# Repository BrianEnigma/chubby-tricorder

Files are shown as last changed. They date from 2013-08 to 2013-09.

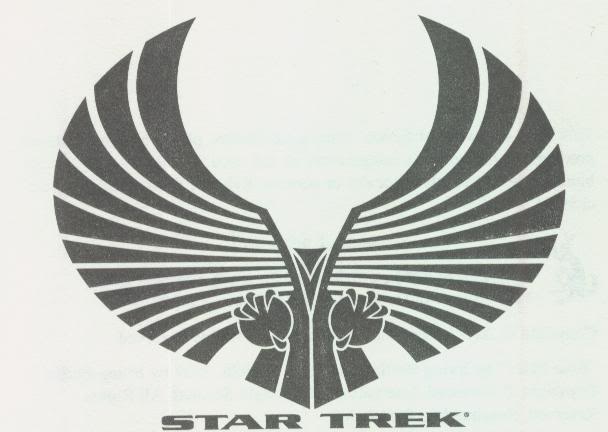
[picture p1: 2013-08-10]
Images/Inspiration/romulan2.jpg

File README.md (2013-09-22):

#The Chubby Tricorder Project



Overview goes here.

#Design Decisions

I cut some corners to accelerate development and minimize risk.  I wanted to work a few weeks of "uh oh" into the timetable as well as be able to focus on the software and presentation.  Namely:

- I used an off-the-shelf microcontroller board: the Arduino.  It's large and a little slow by microcontroller standards, but board bring-up is easy and there are hundreds of premade/pre-tested hardware accessory libraries.
- I used no batteries. The printer eats a ton of power. I didn't want to spend money on hefty batteries, which would tempt prolonged use, which in turn heightens the risk of dead batteries at a critical time.
    - Edit: I used batteries. The puzzle's location changed from indoors to outdoors, so I hacked up a battery pack.
- The case is a simple laser-cut acrylic box of a design similar to the [InfoNinja][] and my [nameplate][] using tabs, slots, and bolted mortise and tension joints. It's entirely right angles, greatly simplifying the design.

[InfoNinja]: http://netninja.com/projects/infoninja/
[nameplate]: http://netninja.com/2012/08/20/a-laser-cut-light-up-nameplate/

#BoM

- Electronics
    - [Arduino](http://www.adafruit.com/products/50)
    - [OLED display](http://www.adafruit.com/products/938)
    - [thermal printer](http://www.adafruit.com/products/597)
    - [thermal paper](http://www.adafruit.com/products/599)
    - [button pad](http://www.adafruit.com/products/419)
    - [illuminated power switch](http://www.adafruit.com/products/482)
    - [panel power connector](http://www.adafruit.com/products/610)
    - RF module
    - [5V 2A AC adapter](http://www.adafruit.com/products/276)
    - assorted bits and bobs
        - hookup wire
        - jumpers, connectors
        - solder
    - tools (soldering iron, wire strippers, diagonal cutters, hot glue gun, etc.)
- laser-cut acrylic parts TODO: public link to files. Materials: $12.00. Cutting: $17.50.
- [black 3M16 screws](http://www.mcmaster.com/#91290a120/=nzdun3)
- [black 3M nuts](http://www.mcmaster.com/#98676a100/=nzdunh)
- [black 2M10 screws](http://www.mcmaster.com/#91290a017/=nzdv42)
- [M2 nuts](http://www.mcmaster.com/#90591a111/=nzdv4x)
- [6mm M3 nylon spacers](http://www.mcmaster.com/#catalog/119/3231/=nze2y8)
- [warranty void stickers](http://www.amazon.com/Silver-Evident-Hologram-Warranty-Stickers/dp/B0049C0MNK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)

#Software Overview

Makes use of the Arduino IDE plus several 3rd party libraries:
- screen
- printer
- button matrix

#Tasks

- [X] Determine pin connections.
- [X] Wire it up on the bench:
    - [X] Test each device, individually:
        - [X] For each external device, on by one, hook it up to the default pins.
        - [X] Verify the library can communicate with the device.
        - [X] Move the device to your desired final set of pins.
        - [X] Verify the library can communicate on the new set of pins.
    - [X] Test all devices in unison:
        - [X] Start with one device, ensure it works.
        - [X] Add another, ensure they work in tandem.
        - [X] Add the next, etc.
- [X] Preliminary software
    - [X] Boot sequence animation (and also print test output on printer?)
    - [X] Data entry screen
    - [X] "Incorrect" animation (with delay to help discourage brute forcing)
    - [X] Several incorrect answers in a row has longer delay?
    - [X] Each "correct" behavior (screen, printer)
- [X] Wireless
    - [X] Transmitter and receiver Hello World
    - [X] Integrate transmitter into design
    - [X] Test with receiver
- [X] Enclosure (black 3MM acrylic)
    - [X] Determine internal parts placement.
    - [X] Preliminary laser cut pattern.
    - [X] Left/Right sides symmetric/interchangeable?
    - [X] Print on paper, verify parts fit, verify pieces interlock correctly.
    - [X] Send to Ponoko.
    - [X] Hole for reprogramming?  "warranty void if removed" sticker?
    - [X] Reinforce printer edge panel
- [X] Battery power
    - [X] Get battery holder
    - [X] Get batteries
    - [X] Wire up to 2.1mm plug
    - [X] Rewire RF to 5V regulator on Arduino
- [ ] Final software
	- [X] Image rotator with PIN entry
	- [X] RF xmission while rotating images
	- [X] Stages of image rotator
	- [X] Easter egg(s)
	- [ ] Better comments
	- [X] Licensing
	- [ ] Publish LCD assistant code separately?
    - [X] Build the more permanent RF receiver device
    - [X] Verify with RF receiver device
    - [X] Verify that one easter egg that wasn't working at meeting
- [X] "Plan B" webapp
	- [X] Basics
	- [X] All content
	- [X] Preload images - skipped; iPhone times out preloading and aborts JavaScript
- [X] Final documentation
	- [X] Prepare github
	- [X] Prepare website
	- [X] Prepare narrative blog post
	- [X] Prepare shortened URL
	- [X] Insert shortened URL plus intro text into code as easter egg

#Away Kit

In the event of a problem during the game, I'll need to assemble an "away kit" with various repair tools.

- allen wrench
- needle-nose pliers
- diagonal clippers
- multimeter
- soldering iron, solder
- helping hands

#License

The Chubby Tricorder (https://github.com/BrianEnigma/chubby-tricorder)by Brian 
Enigma (http://netninja.com) is licensed under a Creative Commons Attribution-ShareAlike 
3.0 Unported License: http://creativecommons.org/licenses/by-sa/3.0/deed.en_US

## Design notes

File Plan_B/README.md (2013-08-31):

#The "Plan B" Tricorder

In the event of a problem, this iPhone webapp can take the place of the Tricorder. Various problems might include:

- Damaged Tricorder
- We get the RF working against test devices, but the Communications Probe and Tricorder simply don't integrate and can't talk to one another.
- RF interference that prevent the two devices from working in particular locations in the field.
- Any and all other sorts of acts of the gods

So this is a webapp that will let you see the various Tricorder screens without needing to communicate via RF to the Communications Probe.

##Prerequisites

You'll need the [iUI-js][iUI] library. Running the Makefile will download, unpack, and rearrange directories for you.

[iUI]: http://www.iui-js.org/download

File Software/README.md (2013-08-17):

#Third Party Components

- [Arduino 1.0.5 IDE](http://www.arduino.cc/en/Main/Software)
- [Matrix Keypad Library 3.0 2012-07-12](http://playground.arduino.cc/Code/Keypad)
- [Adafruit Thermal Printer Library](https://github.com/adafruit/Adafruit-Thermal-Printer-Library)
- [Adafruit GFX Library](https://github.com/adafruit/Adafruit-GFX-Library)
- [Adafruit SSD1306 Library](https://github.com/adafruit/Adafruit_SSD1306)

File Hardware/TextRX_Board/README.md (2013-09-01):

#RX Test Board

This is a board that, for me, takes the place of the Tricorder. It receives signal from the RF module and displays what it has received. It's a quick test/diagnostic device, not meant for anything final. It's just nice to have the build documented and to have it on a laser-cut platform for portability.

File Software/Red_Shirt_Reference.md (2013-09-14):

#Communications Probe: Red Shirt Reference

REPRINT CODE: 911911

##Hints

The first level of hinting for each puzzle is to ensure that Curtis has identified the correct names for each image shown on the tricorder (NOT the communications probe so we preserve some puzzling for figuring out those names once the tricorder pattern is recognized). This can be done in character, “e.g. Sir, perhaps the research we’ve done could identify the names of one or two of those images for you. Which ones would you like to know more about?” followed by “Our research indicates that dog is known as a SCOTTY”. Or if he has any incorrect names, “Our research suggests the name for that image is incorrect.”

If he’s really stuck on the names for any of the communications probe images after understanding the tricorder pattern, we can give those in character as well, but only once it’s clear he understands the tricorder pattern.

##Minipuzzle 1

- Tricorder images: HERO, SAX, ORE, WINE 
- Tricorder numbers: 0, 6, 1, 9
- Communications Probe images: HOUR, NIKE, LIGHT, FILE 
- Communications Probe numbers to enter: 4, 9, 8, 5

Scheme: image name is one letter off from a digit name

Further hints:

- Sir, it looks like those tricorder lights are some kind of encoding.
- Perhaps we should compare each image to the number.
- Maybe if we spelled out those numbers we would find something.

##Minipuzzle 2

- Tricorder images: ARCHER, SCOTTY, YAR, DATA
- Tricorder numbers: 5, 1, 2, 2
- Communications Probe images: QUARK, BONES, 7 OF 9, PARIS 
- Communications Probe numbers to enter: 3, 1, 4, 4

Scheme: the series number the character is from (1=TOS, 2=TNG, 3=DS9, 4=Voyager, 5=Enterprise)

Further hints:

- Sir, our analysis suggests these are all from our universe
- Our research suggests they may be people
- In fact, you might have met Data and Yar
- I think I’ve heard the name Scotty before — wasn’t he from the generation before us?

##Minipuzzle 3

- Tricorder images: BEET, XBOX, RAFT, PEEL
- Tricorder numbers: 14, 3, 13, 7
- Communications Probe images: BATH, TAPE, BOWL, CART 
- Communications Probe numbers to enter: 14, 7, 7, 13

Scheme: The four binary bits of the numbers select letters in the word and vice-versa (beet/bee, xbox/ox, raft/rat, peel/eel, bath/bat, tape/ape, bowl/owl, cart/cat)

Further hints:

- Sir, those words all seem to have 4 letters
- Sir, our analysis suggests the tricorder may be providing some kind of mask
- Our analysis suggests it might be useful to apply the 4-light mask to each word

##Minipuzzle 4

For the initial hinting to give Curtis the full set of names, provide only the names of the items, not the color in parentheses that they suggest.

- Tricorder images: MARS (THE RED PLANET), WASP (YELLOW JACKET), FRANK SINATRA (OLD BLUE EYES), CAKE (RED VELVET CAKE, SPECIFICALLY) 
- Tricorder numbers: 1, 3, 5, 1
- Communications Probe images: SEATTLE (THE EMERALD CITY), GARDENER (GREEN THUMB), SAD PERSON (FEELING BLUE), IBM (BIG BLUE) 
- Communications Probe numbers to enter: 4, 4, 5, 5

Scheme: color indexes into the rainbow (ROYGBIV)

Further hints:

- Sir, our research suggests that the humanoid known as Frank Sinatra ha d a nickname.
- Sir, our research suggests that this may be a specific type of cake.
- We’re seeing that the planet Mars may also have a nickname.
- Some of those nicknames look quite colorful.
- If he isn’t aware of the color nicknames/names for these, provide them (e.g. Sir, it turns out Frank Sinatra was known as Old Blue Eyes).

##Minipuzzle 5

- Tricorder images: WONDER BREAD, ANALGESICS, GATORADE, GEORDI LA FORGE
- Tricorder numbers: 1, 6, 8, 4
- Communications Probe images: UNIFORM, CANINE, SKATER, TEST TUBE
- Communications Probe numbers to enter: 4, 9, 8, 2

Scheme: number contained in the phonemes of the words (Gateorade/eight, La Forge/four)

Further hints:

- Sir, these words certainly do *sound* very interesting.
- Hmmm... WON-der bread, what could that be trying to tell us? (continue with this approach a few times)

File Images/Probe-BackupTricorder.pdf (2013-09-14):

## Emergency Backup Tricorder

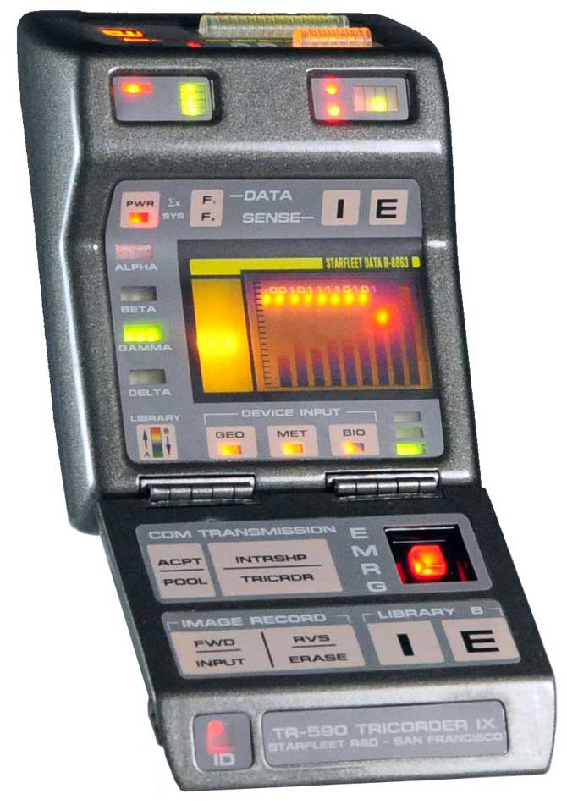
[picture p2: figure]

An Emergency Backup Tricorder may be found at the following Uniform Resource Locator:
http://nja.me/3cord

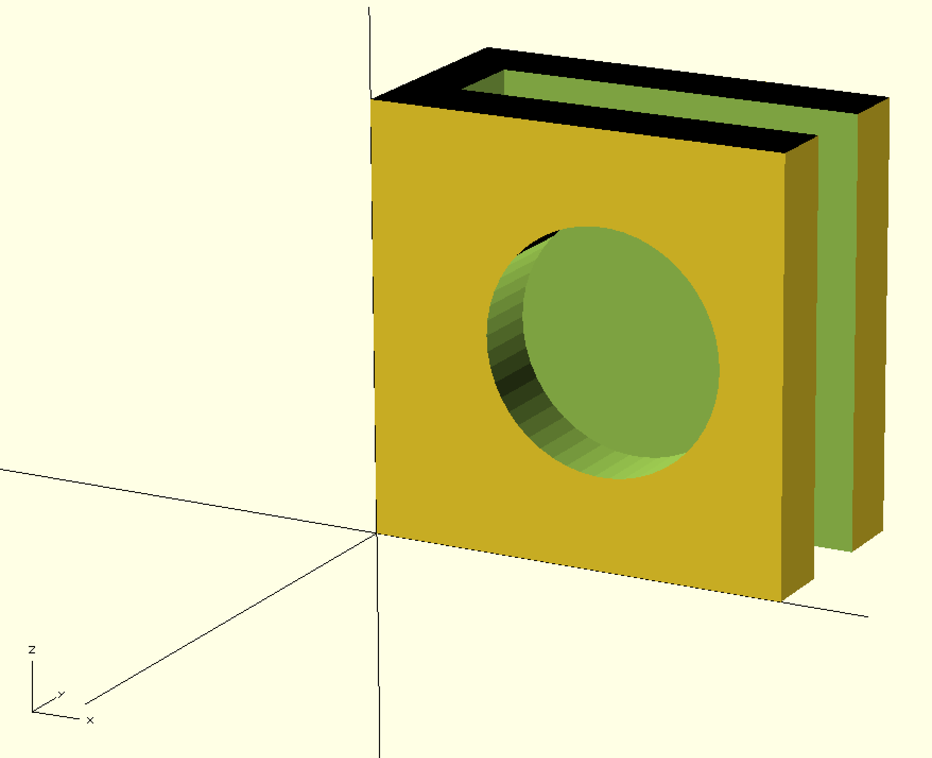
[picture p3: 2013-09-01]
Hardware/Brackets/RF_Module_Bracket.png

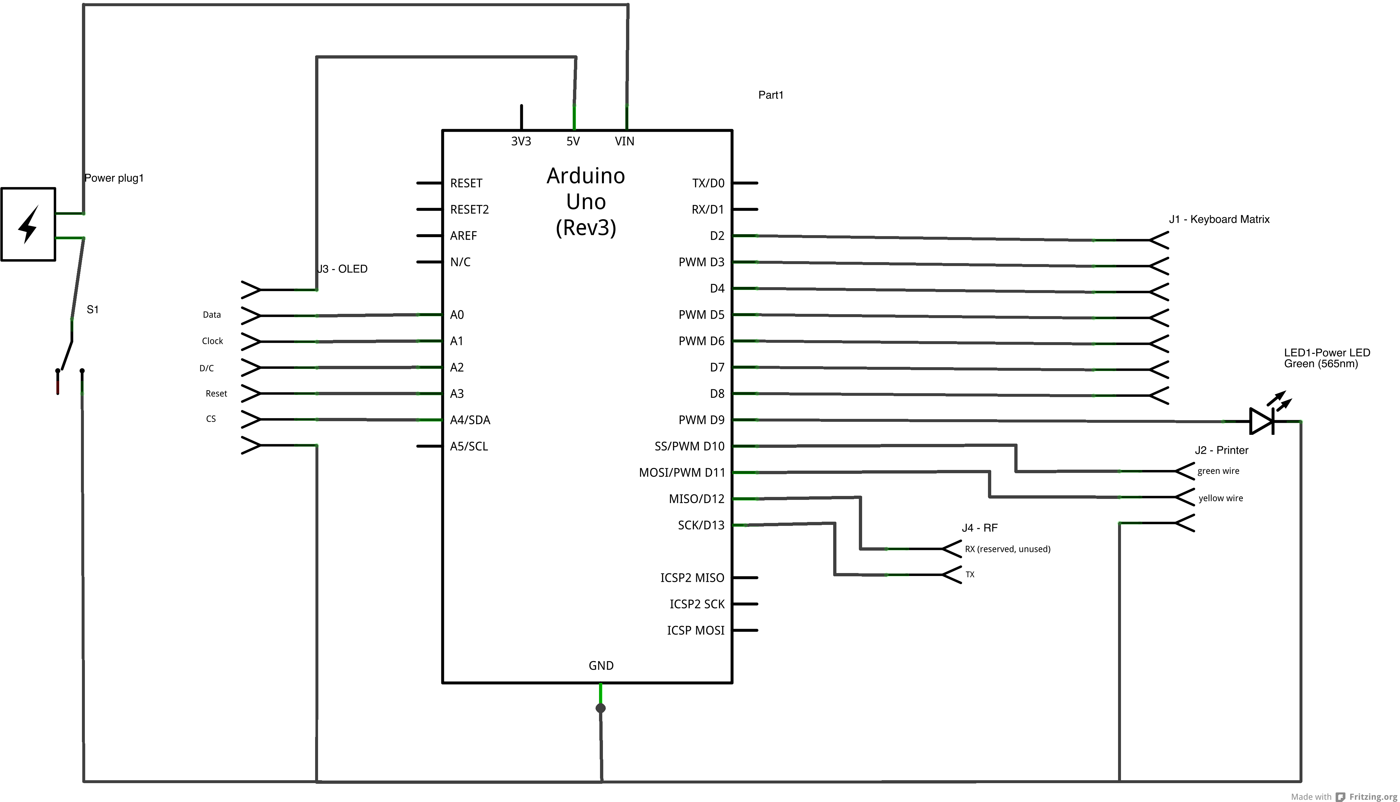
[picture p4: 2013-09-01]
Hardware/Electronics/Chubby_Tricorder_schem.png

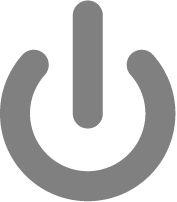
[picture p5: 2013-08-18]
Hardware/Case/IEC5009_Standby_Symbol.png

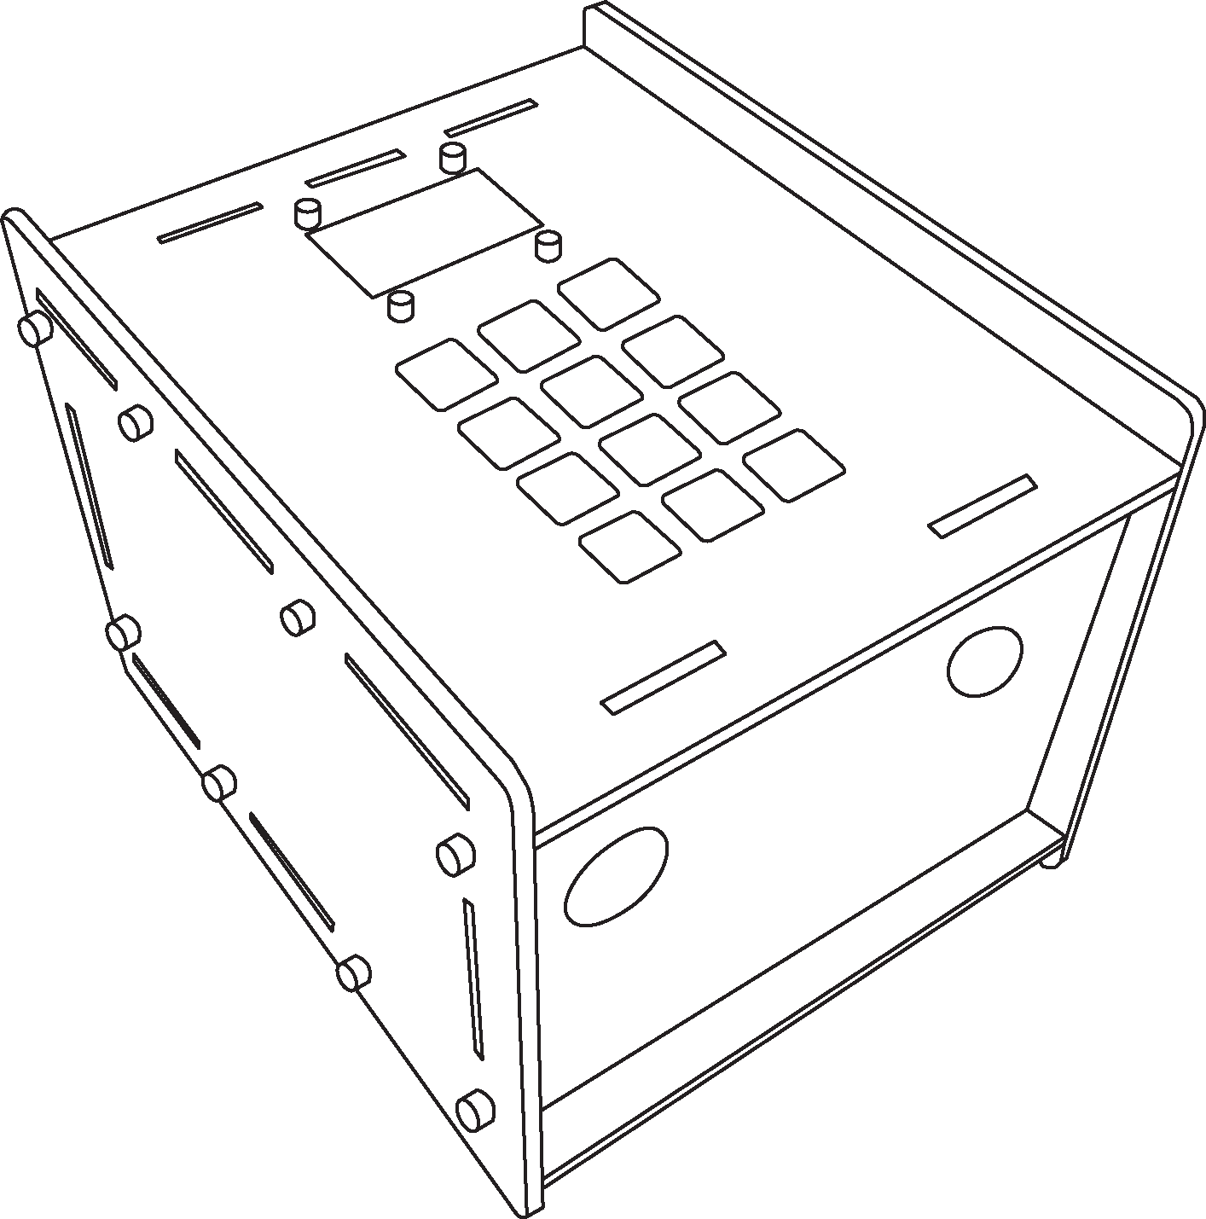
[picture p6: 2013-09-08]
Images/probe-trace.png

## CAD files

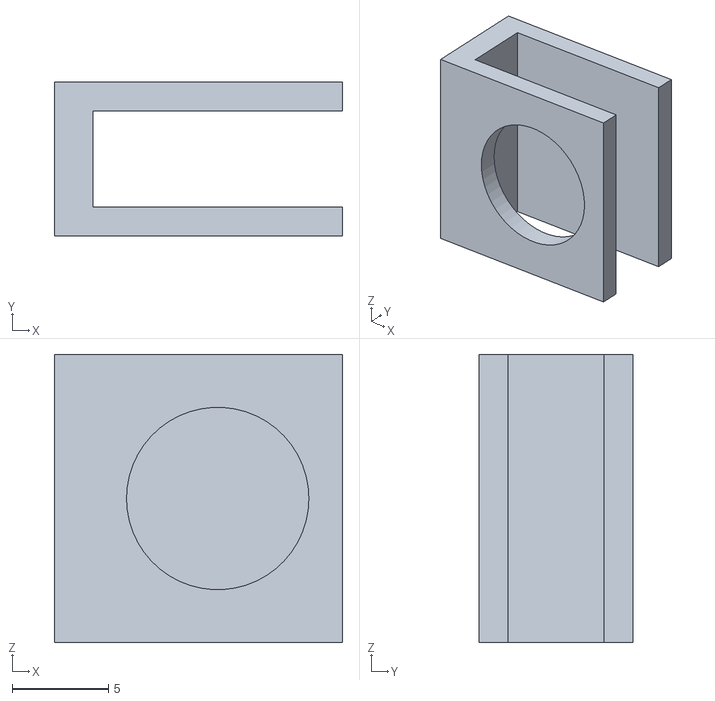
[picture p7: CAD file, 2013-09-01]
Hardware/Brackets/RF_Module_Bracket.stl
15.0 x 8.00 x 15.0

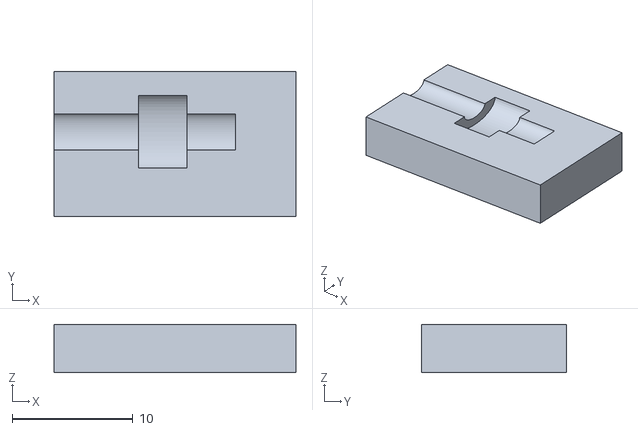
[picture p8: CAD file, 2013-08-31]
Hardware/Brackets/3d_printed_brace-1.stl
20.0 x 12.0 x 4.00

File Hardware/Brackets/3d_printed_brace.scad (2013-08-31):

CUBE_X = 20;
CUBE_Y = 12;
CUBE_Z = 4;

EDGE_OFFSET = 5;

SQUISH = 0.5;
DETAIL = 50;

// Uncomment only one of the following lines to get
// braces for each of the four corners:

//scale(v = [-1, -1, 1])
//scale(v = [1, -1, 1])
//scale(v = [-1, 1, 1])
scale(v = [1, 1, 1])

    translate(v = [CUBE_X / -2, CUBE_Y / -2, 0])
        difference()
        {
            cube(size = [CUBE_X, CUBE_Y, CUBE_Z]);
            translate(v = [-1, CUBE_Y - EDGE_OFFSET, CUBE_Z])
                scale(v = [1, 1, SQUISH])
                    rotate(a = [0, 90, 0])
                        cylinder(h = 15 + 1, r = 1.5, $fn = DETAIL);
            translate(v = [7, CUBE_Y - EDGE_OFFSET, CUBE_Z])
                scale(v = [1, 1, SQUISH])
                    rotate(a = [0, 90, 0])
                        cylinder(h = 4, r = 3, $fn = DETAIL);
        }

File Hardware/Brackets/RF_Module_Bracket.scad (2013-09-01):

difference()
{
    // Overall boundary
    cube(size=[15, 8, 15]);
    // Carve out slot
    translate(v = [2, 1.5, -1])
        cube(size = [15, 5, 17]);
    // Carve out circle
    translate(v = [7.5 + 1, 3, 7.5])
        rotate(a = [90, 0, 0])
            cylinder(h = 10, r = 4.75, $fn=50);
}

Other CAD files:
Hardware/Brackets/3d_printed_brace-2.stl
Hardware/Brackets/3d_printed_brace-3.stl
Hardware/Brackets/3d_printed_brace-4.stl

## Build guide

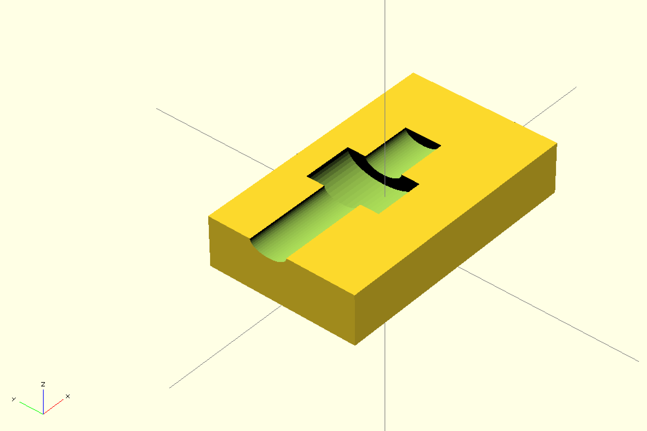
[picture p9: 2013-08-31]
Hardware/Brackets/3d_printed_brace.png

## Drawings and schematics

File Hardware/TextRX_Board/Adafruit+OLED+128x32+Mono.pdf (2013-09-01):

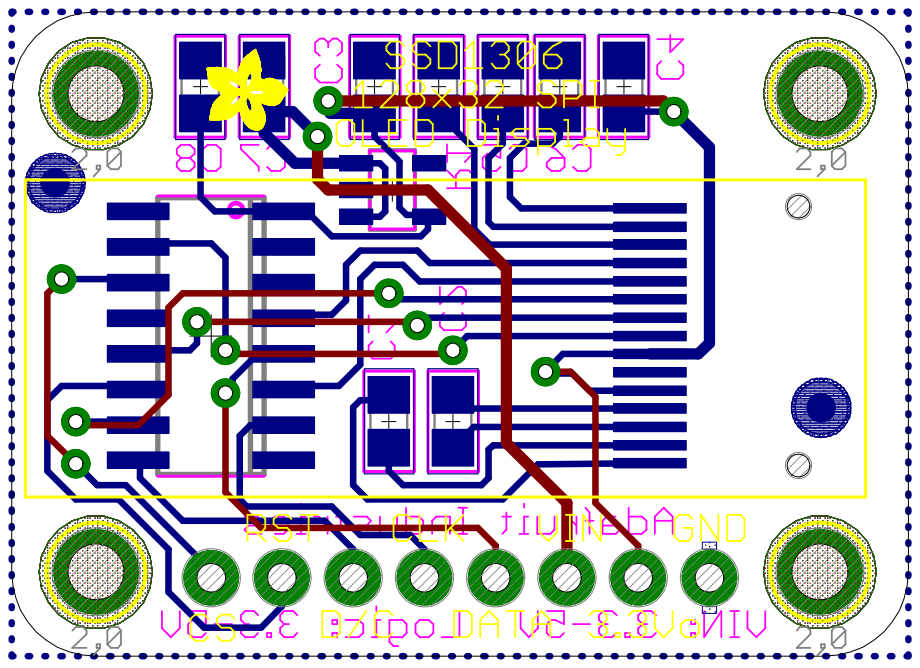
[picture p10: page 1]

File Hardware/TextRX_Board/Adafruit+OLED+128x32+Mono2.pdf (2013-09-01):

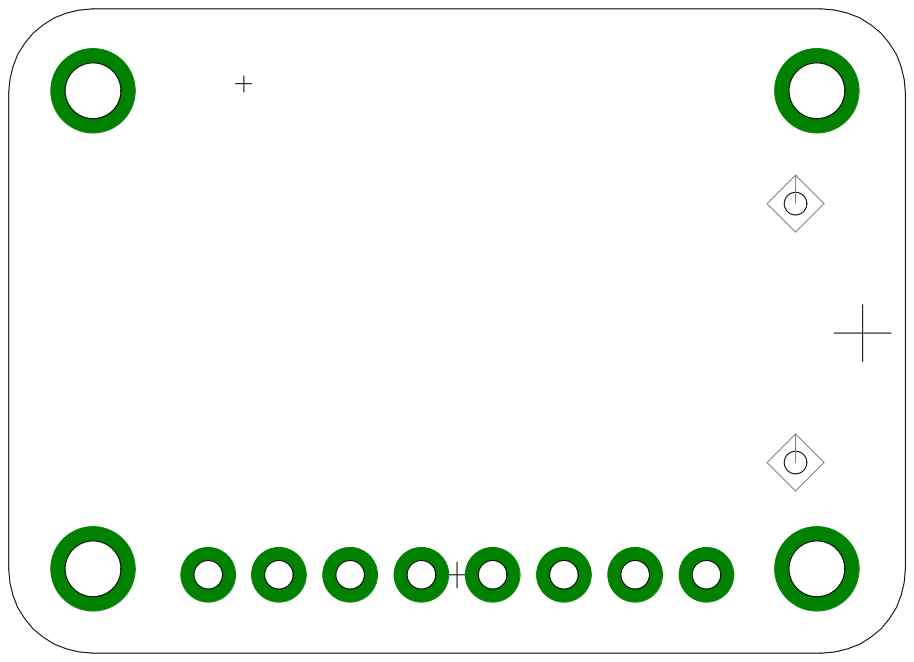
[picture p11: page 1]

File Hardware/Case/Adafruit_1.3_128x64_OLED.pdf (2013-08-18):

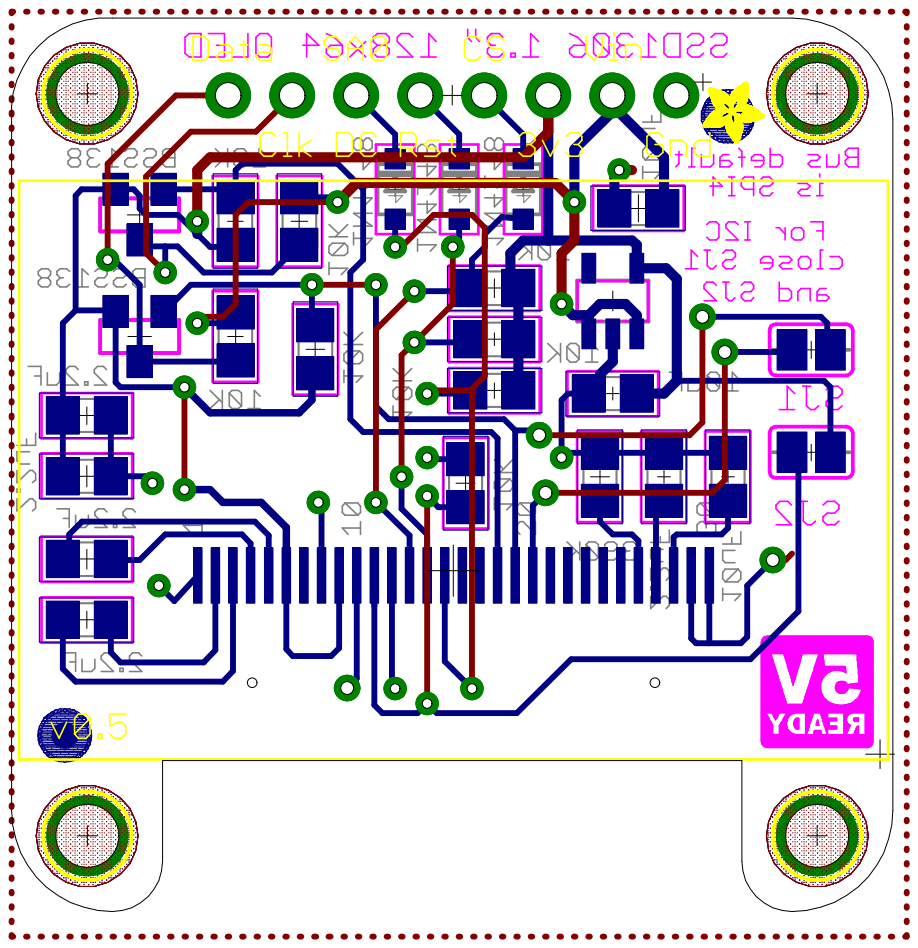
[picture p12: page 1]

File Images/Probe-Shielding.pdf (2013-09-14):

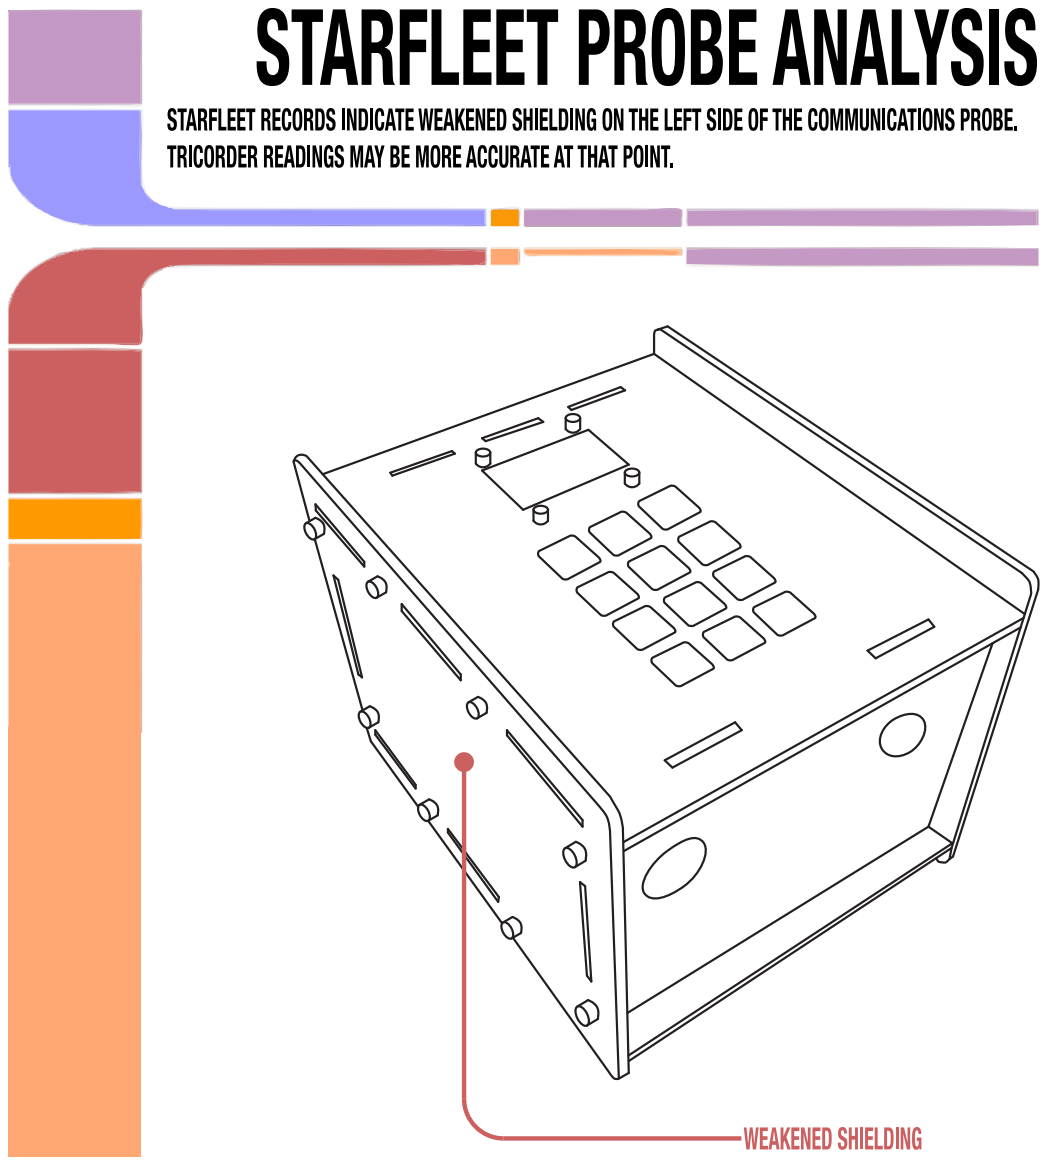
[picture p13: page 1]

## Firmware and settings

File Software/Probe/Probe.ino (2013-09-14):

#include <Wire.h>
#include <Keypad.h>
#include <Adafruit_GFX.h>
#include <Adafruit_SSD1306.h>
#include <SoftwareSerial.h>
#include "Adafruit_Thermal.h"
#include <avr/pgmspace.h>

// Debug settings
//#define DEBUG_FAST_STARTUP_ANIM
//#define DEBUG_SKIP_STARTUP

// #######################################################
// IMAGES BEGIN
// Really, Arduino IDE??? These have to be inline and not in an include file?
#define PROBE1_1_WIDTH  56
#define PROBE1_1_HEIGHT 56
#define PROBE1_1_X  36
#define PROBE1_1_Y 0
static unsigned char PROGMEM PROBE1_1[] = {
0x00,0x00,0x00,0x00,0x00,0x00,0x00,0x00,0x00,0x05,0x7D,0x40,0x00,0x00,0x00,0x00
,0x15,0x00,0xA8,0x00,0x00,0x00,0x00,0xB0,0x04,0x0A,0x00,0x00,0x00,0x01,0x40,0x6E
,0x02,0x80,0x00,0x00,0x06,0x00,0x0A,0x00,0xE0,0x00,0x00,0x08,0x00,0x68,0x00,0x10
,0x00,0x00,0x2B,0x40,0x3A,0x03,0x14,0x00,0x00,0x21,0x40,0x1C,0x02,0x02,0x00,0x00
,0xC1,0x40,0x18,0x02,0x02,0x00,0x01,0x02,0x40,0x18,0x03,0x01,0x00,0x01,0x00,0x40
,0x00,0x00,0x00,0x80,0x05,0x00,0x00,0x08,0x00,0x00,0x40,0x02,0x00,0x00,0x08,0x00
,0x06,0x40,0x04,0x00,0x00,0x00,0x00,0x05,0x30,0x0D,0x70,0x00,0x08,0x00,0x01,0x20
,0x09,0x50,0x00,0x08,0x00,0x02,0x10,0x11,0xD0,0x00,0x08,0x00,0x07,0x08,0x11,0x60
,0x00,0x08,0x00,0x00,0x00,0x20,0x00,0x00,0x08,0x00,0x00,0x0C,0x10,0x00,0x00,0x08
,0x00,0x00,0x08,0x20,0x00,0x00,0x08,0x00,0x00,0x04,0x40,0x00,0x00,0x08,0x00,0x00
,0x04,0x20,0x00,0x00,0x08,0x00,0x00,0x02,0x00,0x00,0x00,0x08,0x00,0x00,0x44,0x44
,0x00,0x00,0x08,0x00,0x00,0xE2,0x2A,0x00,0x00,0x08,0x00,0x00,0x20,0x4B,0x00,0x00
,0x18,0x00,0x00,0x96,0x4B,0x00,0x00,0x1C,0x00,0x00,0x92,0x0A,0x00,0x00,0x0A,0x00
,0x00,0x62,0x60,0x00,0x00,0x01,0x80,0x00,0x00,0x00,0x00,0x00,0x00,0x40,0x00,0x02
,0x40,0x00,0x00,0x00,0x30,0x00,0x02,0x20,0x00,0x00,0x00,0x0D,0x00,0x02,0x20,0x00
,0x00,0x00,0x03,0xC0,0x08,0x20,0x00,0x00,0x00,0x03,0xE0,0x04,0x11,0x40,0x00,0x00
,0x01,0xF1,0x08,0x11,0x40,0x00,0x0F,0xE0,0x13,0x08,0x09,0x60,0x00,0x07,0xFC,0x01
,0x88,0x09,0x20,0x00,0x0F,0xF8,0x01,0x20,0x04,0xC0,0x00,0x3F,0xF0,0x01,0x30,0x0C
,0x00,0x01,0xFF,0xE0,0x00,0x20,0x02,0x00,0x07,0xFF,0xE0,0x00,0x20,0x02,0x00,0x1F
,0xFF,0xC0,0x00,0xC0,0x01,0x01,0xFF,0xFD,0xC1,0x00,0x80,0x00,0x83,0xFF,0xF0,0x82
,0x03,0x00,0x00,0xAF,0xFF,0xC0,0x01,0x00,0x00,0x00,0x7F,0xFF,0x18,0x05,0x8C,0x00
,0x00,0x7F,0xFC,0x04,0x02,0x88,0x00,0x03,0xFF,0xF0,0x38,0x00,0x30,0x00,0x03,0xFF
,0x80,0x24,0x00,0xC0,0x00,0x01,0xFF,0x40,0x18,0x07,0x80,0x00,0x01,0xF8,0x28,0x00
,0x14,0x00,0x00,0x00,0xE0,0x15,0x4A,0xE8,0x00,0x00,0x00,0x80,0x01,0x2D,0x00,0x00
,0x00,0x00,0x00,0x00,0x00,0x00,0x00,0x00};
#define PROBE1_2_WIDTH  116
#define PROBE1_2_HEIGHT 44
#define PROBE1_2_X  6
#define PROBE1_2_Y 6
static unsigned char PROGMEM PROBE1_2[] = {
0x00,0x00,0x00,0x00,0x00,0x00,0x00,0x00,0x00,0x00,0x00,0x00,0x00,0x00,0x00,0x00
,0x00,0x00,0x00,0x00,0x00,0x00,0x00,0x00,0x00,0x00,0x00,0x00,0x00,0x00,0x00,0x00
,0x00,0x00,0x00,0x00,0x00,0x00,0x00,0x00,0x00,0x00,0x00,0x00,0x00,0x00,0x00,0x00
,0x00,0x00,0x00,0x00,0x00,0x00,0x00,0x00,0x00,0x00,0x00,0x00,0x00,0x00,0x00,0x00
,0x00,0x00,0x00,0x00,0x00,0x00,0x00,0x00,0x00,0x01,0x00,0x00,0x00,0x80,0x00,0x00
,0x00,0x00,0x00,0x00,0x00,0x00,0x00,0x00,0x1C,0x00,0x00,0x01,0x00,0x00,0x00,0x00
,0x00,0x00,0x00,0x00,0x00,0x00,0x01,0xE0,0x00,0x00,0x03,0x00,0x00,0x00,0x00,0x00
,0x00,0x00,0x00,0x00,0x00,0x1F,0x80,0x00,0x00,0x03,0x00,0x00,0x00,0x00,0x00,0x00
,0x00,0x00,0x00,0x00,0xFE,0x00,0x00,0x00,0x0E,0x00,0x00,0x00,0x00,0x00,0x00,0x00
,0x00,0x00,0x0F,0xF0,0x00,0x00,0x00,0x0E,0x00,0x00,0x00,0x00,0x00,0x00,0x00,0x00
,0x00,0xFF,0xC0,0x00,0x00,0x00,0x1C,0x00,0x00,0x00,0x00,0x00,0x00,0x00,0x00,0x0F
,0xFE,0x00,0x00,0x00,0x00,0x3C,0x00,0x00,0x00,0x00,0x00,0x00,0x00,0x00,0x7F,0xF8
,0x00,0x00,0x00,0x00,0x7C,0x00,0x00,0x00,0x00,0x00,0x00,0x00,0x07,0xFF,0xE0,0x00
,0x00,0x00,0x00,0x7C,0x00,0x00,0x00,0x00,0x00,0x00,0x00,0x7F,0xFF,0x00,0x00,0x00
,0x00,0x00,0xFC,0x00,0x00,0x00,0x00,0x00,0x00,0x07,0xFF,0xFC,0x00,0x00,0x00,0x00
,0x01,0xFC,0x00,0x00,0x00,0x00,0x00,0x00,0x3F,0xFF,0xF0,0x00,0x00,0x00,0x00,0x01
,0xFC,0x00,0x00,0x00,0x00,0x00,0x07,0xFF,0xFF,0x80,0x00,0x00,0x00,0x00,0x03,0xFC
,0x00,0x00,0x00,0x00,0x00,0x3F,0xFF,0xFE,0x00,0x00,0x00,0x00,0x00,0x07,0xFC,0x00
,0x00,0x00,0x00,0x03,0xFF,0xFF,0xF0,0x00,0x00,0x00,0x00,0x00,0x07,0xFE,0x00,0x00
,0x00,0x00,0x3F,0xFF,0xFF,0xC0,0x00,0x00,0x00,0x00,0x00,0x07,0xFE,0x00,0x00,0x00
,0x01,0xFF,0xFF,0xFF,0x00,0x00,0x00,0x00,0x00,0x00,0x0F,0xFF,0x00,0x00,0x00,0x1F
,0xFF,0xFF,0xF8,0x00,0x00,0x00,0x00,0x00,0x00,0x0F,0xFF,0x80,0x00,0x01,0xFF,0xFF
,0xFF,0xE0,0x00,0x00,0x00,0x00,0x00,0x00,0x1F,0xFF,0xC0,0x00,0x0F,0xFF,0xFF,0xFF
,0x80,0x00,0x00,0x00,0x00,0x00,0x00,0x1F,0xFF,0xF0,0x01,0xFF,0xFF,0xFF,0xFC,0x00
,0x00,0x00,0x00,0x00,0x00,0x00,0x1F,0xFF,0xFF,0xFF,0xFF,0xFF,0xFF,0xF0,0x00,0x00
,0x00,0x00,0x00,0x00,0x00,0x1F,0xFF,0xFF,0xFF,0xFF,0xFF,0xFF,0xC0,0x00,0x00,0x00
,0x00,0x00,0x00,0x00,0x3F,0xFF,0xFF,0xFF,0xFF,0xFF,0xFE,0x00,0x00,0x00,0x00,0x00
,0x00,0x00,0x00,0x3F,0xFF,0xFF,0xFF,0xFF,0xFF,0xF8,0x00,0x00,0x00,0x00,0x00,0x00
,0x00,0x00,0x3F,0xFF,0xFF,0xFF,0xFF,0xFF,0xE0,0x00,0x00,0x00,0x00,0x00,0x00,0x00
,0x00,0x3F,0xFF,0xFF,0xFF,0xFF,0xFF,0x00,0x00,0x00,0x00,0x00,0x00,0x00,0x00,0x00
,0x3F,0xFF,0xFF,0xFF,0xFF,0xFC,0x00,0x00,0x00,0x00,0x00,0x00,0x00,0x00,0x00,0x1F
,0xFF,0xFF,0xFF,0xFF,0xE0,0x00,0x00,0x00,0x00,0x00,0x00,0x00,0x00,0x00,0x1F,0xFF
,0xFF,0xFF,0xFF,0x80,0x00,0x00,0x00,0x00,0x00,0x00,0x00,0x00,0x00,0x1F,0xFF,0xFF
,0xFF,0xFC,0x00,0x00,0x00,0x00,0x00,0x00,0x00,0x00,0x00,0x00,0x1F,0xFF,0xFF,0xFF
,0xF8,0x00,0x00,0x00,0x00,0x00,0x00,0x00,0x00,0x00,0x00,0x0F,0xFF,0xFF,0xFF,0xC0
,0x00,0x00,0x00,0x00,0x00,0x00,0x00,0x00,0x00,0x00,0x07,0xFF,0xFF,0xFF,0x00,0x00
,0x00,0x00,0x00,0x00,0x00,0x00,0x00,0x00,0x00,0x03,0xFF,0xFF,0xF8,0x00,0x00,0x00
,0x00,0x00,0x00,0x00,0x00,0x00,0x00,0x00,0x01,0xFF,0xFF,0xE0,0x00,0x00,0x00,0x00
,0x00,0x00,0x00,0x00,0x00,0x00,0x00,0x00,0x7F,0xFC,0x00,0x00,0x00,0x00,0x00,0x00
,0x00,0x00,0x00,0x00,0x00,0x00,0x00,0x0B,0x40,0x00,0x00,0x00,0x00,0x00,0x00,0x00
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
#define PROBE1_3_WIDTH  34
#define PROBE1_3_HEIGHT 56
#define PROBE1_3_X  47
#define PROBE1_3_Y 0
static unsigned char PROGMEM PROBE1_3[] = {
0x00,0x07,0xF8,0x00,0x00,0x00,0x30,0x07,0x00,0x00,0x00,0x40,0x00,0xC0,0x00,0x01
,0x80,0x00,0x20,0x00,0x02,0x00,0x00,0x18,0x00,0x04,0x00,0x00,0x04,0x00,0x08,0x00
,0x00,0x04,0x00,0x10,0x00,0x00,0x02,0x00,0x10,0x00,0x00,0x01,0x00,0x20,0x00,0x00
,0x01,0x00,0x40,0x00,0x00,0x00,0x80,0x40,0x00,0x00,0x00,0x80,0x40,0x00,0x00,0x00
,0x00,0x80,0x00,0x00,0x00,0x40,0x80,0x00,0x00,0x00,0x40,0x80,0x00,0x40,0x00,0x40
,0x80,0x12,0xD8,0x00,0x40,0x80,0x1D,0xB2,0x00,0x00,0x80,0x09,0x2E,0x00,0x40,0x80
,0x08,0x00,0x00,0x00,0x80,0x08,0x04,0x00,0x40,0x80,0x08,0x04,0x00,0x40,0x80,0x00
,0x04,0x00,0x40,0x40,0x04,0x00,0x00,0x40,0x40,0x04,0x08,0x00,0x40,0x40,0x04,0x08
,0x00,0x80,0x20,0x04,0x10,0x00,0x80,0x20,0x02,0x10,0x00,0x80,0x00,0x02,0x10,0x01
,0x00,0x10,0x02,0x00,0x01,0x00,0x08,0x02,0x20,0x02,0x00,0x08,0x02,0x20,0x04,0x00
,0x04,0x02,0x20,0x08,0x00,0x02,0x02,0x20,0x08,0x00,0x02,0x02,0x20,0x10,0x00,0x01
,0x02,0x20,0x20,0x00,0x01,0x02,0x20,0x20,0x00,0x00,0x82,0x20,0x40,0x00,0x00,0x82
,0x20,0x00,0x00,0x00,0x82,0x20,0x80,0x00,0x00,0x82,0x20,0x80,0x00,0x00,0x82,0x20
,0x80,0x00,0x00,0x82,0x20,0x80,0x00,0x00,0x62,0x23,0x00,0x00,0x00,0x7F,0xFF,0x00
,0x00,0x00,0x7F,0xFF,0x00,0x00,0x00,0x3F,0xFE,0x00,0x00,0x00,0x7F,0xFE,0x00,0x00
,0x00,0x7F,0xFF,0x00,0x00,0x00,0x7F,0xFE,0x00,0x00,0x00,0x7F,0xFF,0x00,0x00,0x00
,0x3F,0xFE,0x00,0x00,0x00,0x3F,0xFE,0x00,0x00,0x00,0x1F,0xFC,0x00,0x00,0x00,0x0F
,0xF0,0x00,0x00,0x00,0x03,0xE0,0x00,0x00};
#define PROBE1_4_WIDTH  73
#define PROBE1_4_HEIGHT 56
#define PROBE1_4_X  28
#define PROBE1_4_Y 0
static unsigned char PROGMEM PROBE1_4[] = {
0x00,0x00,0x00,0x00,0x00,0x00,0x00,0x00,0x00,0x00,0x03,0xE0,0x00,0x00,0x00,0x00
,0x00,0x00,0x00,0x00,0x0F,0xF0,0x00,0x00,0x00,0x00,0x00,0x00,0x00,0x00,0x1B,0xB8
,0x00,0x00,0x00,0x00,0x00,0x00,0x00,0x00,0x7F,0xFF,0x00,0x00,0x00,0x00,0x00,0x00
,0x00,0x00,0x7F,0xFF,0x00,0x00,0x00,0x00,0x00,0x00,0x00,0x00,0x17,0xFF,0xC0,0x00
,0x00,0x00,0x00,0x00,0x00,0x00,0x0B,0xBE,0xE0,0x00,0x00,0x00,0x00,0x00,0x00,0x00
,0x07,0xFF,0x70,0x00,0x00,0x00,0x00,0x00,0x00,0x00,0x03,0x7F,0xBE,0x00,0x00,0x00
,0x00,0x00,0x00,0x00,0x00,0xFF,0xDF,0x00,0x00,0x00,0x00,0x00,0x00,0x00,0x00,0x2B
,0x7E,0xC0,0x00,0x00,0x00,0x00,0x00,0x00,0x00,0x17,0xFF,0xC0,0x00,0x00,0x00,0x00
,0x00,0x00,0x00,0x0A,0xBF,0xB0,0x00,0x00,0x00,0x00,0x00,0x00,0x00,0x03,0xFF,0xFC
,0x00,0x00,0x00,0x00,0x00,0x00,0x00,0x01,0xFB,0xEE,0x00,0x00,0x00,0x00,0x00,0x00
,0x00,0x00,0x57,0xFF,0xC0,0x00,0x00,0x00,0x00,0x00,0x00,0x00,0x28,0xF3,0xC0,0x00
,0x00,0x00,0x00,0x00,0x00,0x00,0x17,0x9F,0xF0,0x00,0x00,0x00,0x00,0x00,0x00,0x00
,0x07,0xE8,0xE8,0x00,0x00,0x00,0x00,0x00,0x00,0x00,0x07,0xFF,0xFE,0x00,0x00,0x00
,0x00,0x00,0x00,0x00,0x00,0x7B,0xE6,0x00,0x00,0x00,0x00,0x00,0x00,0x00,0x00,0x5F
,0xDF,0xC0,0x00,0x00,0x00,0x00,0x00,0x00,0x00,0x2E,0xFB,0xA0,0x00,0x00,0x00,0x00
,0x00,0x00,0x00,0x0F,0xFF,0xFC,0x00,0x00,0x00,0x00,0x00,0x00,0x00,0x07,0xEE,0xFE
,0x00,0x00,0x00,0x00,0x00,0x00,0x00,0x01,0xF7,0xD7,0x00,0x00,0x00,0x00,0x00,0x00
,0x00,0x00,0xFB,0x8B,0x80,0x00,0x00,0x00,0x00,0x00,0x00,0x00,0x5F,0x7F,0x70,0x00
,0x00,0x00,0x00,0x00,0x00,0x00,0x0B,0x3E,0x78,0x00,0x00,0x00,0x00,0x00,0x00,0x00
,0x0D,0xF7,0xDC,0x00,0x00,0x00,0x00,0x00,0x00,0x00,0x02,0xFC,0xF2,0x00,0x00,0x00
,0x00,0x00,0x00,0x00,0x01,0xFF,0xF3,0x80,0x00,0x00,0x00,0x00,0x00,0x00,0x00,0x7F
,0x3A,0x80,0x00,0x00,0x00,0x00,0x00,0x00,0x00,0x17,0x00,0x40,0x00,0x00,0x00,0x00
,0x00,0x00,0x00,0x0A,0xA0,0x60,0x00,0x00,0x00,0x00,0x00,0x00,0x00,0x0F,0xC0,0x60
,0x00,0x00,0x00,0x00,0x00,0x00,0x00,0x01,0xF0,0x00,0x00,0x00,0x00,0x00,0x00,0x00
,0x00,0x00,0xCC,0x18,0x00,0x00,0x00,0x00,0x00,0x00,0x00,0x00,0x0A,0x83,0xE0,0x00
,0x00,0x00,0x00,0x00,0x00,0x00,0x01,0xE4,0x30,0x00,0x00,0x00,0x00,0x00,0x00,0x00
,0x00,0x6C,0x10,0x00,0x00,0x00,0x00,0x00,0x00,0x00,0x00,0x18,0x08,0x00,0x00,0x00
,0x00,0x00,0x00,0x00,0x00,0x18,0x04,0x00,0x00,0x00,0x00,0x00,0x00,0x00,0x00,0x18
,0x03,0x00,0x00,0x00,0x00,0x00,0x00,0x00,0x00,0x08,0x00,0x00,0x00,0x00,0x00,0x00
,0x00,0x00,0x00,0x0C,0x00,0x80,0x00,0x00,0x00,0x00,0x00,0x00,0x00,0x02,0x00,0x00
,0x00,0x00,0x00,0x00,0x00,0x00,0x00,0x01,0xC0,0x00,0x00,0x00,0x00,0x00,0x00,0x00
,0x00,0x00,0x60,0x00,0x00,0x00,0x00,0x00,0x00,0x00,0x00,0x00,0x18,0x00,0x00,0x00
,0x00,0x00,0x00,0x00,0x00,0x00,0x08,0x00,0x00,0x00,0x00,0x00,0x00,0x00,0x00,0x00
,0x04,0x00,0x00,0x00,0x00,0x00,0x00,0x00,0x00,0x00,0x02,0x00,0x00,0x00,0x00,0x00
,0x00,0x00,0x00,0x00,0x01,0x00,0x00,0x00,0x00,0x00,0x00,0x00,0x00,0x00,0x00,0x80
};
#define PROBE2_1_WIDTH  63
#define PROBE2_1_HEIGHT 56
#define PROBE2_1_X  33
#define PROBE2_1_Y 0
static unsigned char PROGMEM PROBE2_1[] = {
0x00,0x00,0x06,0x20,0x00,0x00,0x00,0x00,0x00,0x00,0x60,0x01,0x00,0x00,0x00,0x00
,0x00,0x00,0x00,0x00,0x10,0x00,0x00,0x00,0x00,0x04,0x00,0x00,0x00,0x00,0x00,0x00
,0x00,0x00,0x00,0x00,0x02,0x00,0x00,0x00,0x00,0x60,0x00,0x00,0x00,0x00,0x00,0x00
,0x00,0x00,0x00,0x00,0x00,0x00,0x00,0x00,0x00,0x00,0x00,0x00,0x00,0x20,0x00,0x00
,0x02,0x00,0x00,0x00,0x00,0x00,0x00,0x00,0x00,0x07,0xE0,0x00,0xF8,0x00,0x00,0x00
,0x00,0x1C,0x38,0x07,0x0E,0x00,0x00,0x00,0x08,0x30,0x0C,0x0C,0x01,0x04,0x00,0x00
,0x10,0x60,0x02,0x10,0x00,0x80,0x00,0x00,0x00,0x80,0x41,0x30,0x10,0x40,0x00,0x00
,0x00,0x80,0x61,0x20,0x18,0x21,0x00,0x00,0x41,0x80,0x61,0xA0,0x08,0x20,0x80,0x00
,0x01,0x00,0xE0,0xE0,0x38,0x20,0x00,0x00,0x01,0x07,0xE0,0xE1,0xF8,0x20,0x00,0x00
,0x01,0x0E,0x40,0xE3,0x98,0x20,0x00,0x00,0x01,0x0E,0xC0,0xE3,0x98,0x20,0xC0,0x00
,0x81,0x0E,0xC0,0xE3,0xB8,0x20,0x00,0x00,0x01,0x87,0xC1,0xA1,0xF0,0x20,0x00,0x00
,0x00,0x80,0x01,0x20,0x00,0x40,0x00,0x00,0x80,0x40,0x02,0x10,0x00,0xC0,0x40,0x00
,0x80,0x20,0x06,0x08,0x01,0x80,0x40,0x00,0x80,0x18,0x18,0x06,0x02,0x00,0x40,0x00
,0x00,0x0F,0xFF,0xFF,0xFC,0x00,0x40,0x00,0x00,0x00,0x08,0x06,0x00,0x00,0x00,0x00
,0x00,0x00,0x10,0x03,0x00,0x60,0x00,0x00,0x80,0x00,0x20,0x01,0x80,0xE0,0x00,0x00
,0x00,0x00,0x40,0x00,0x80,0xE0,0x40,0x00,0x00,0x00,0x40,0x00,0x41,0xE0,0xC0,0x00
,0x00,0x00,0x41,0x98,0x47,0xFF,0xFF,0xFE,0x40,0x00,0x81,0x98,0x47,0xFF,0xFF,0xFE
,0x00,0x00,0x81,0xB8,0x4F,0xFF,0xFF,0xFE,0x00,0x00,0x81,0xB0,0x4F,0xFF,0xFF,0xFE
,0x10,0x00,0x81,0xF8,0x47,0xFF,0xFF,0xFE,0x18,0x00,0x40,0x00,0x43,0xFF,0xFF,0xFE
,0x00,0x00,0x40,0x00,0xC1,0xE4,0x00,0x00,0x00,0x00,0x60,0x00,0x80,0xE0,0x00,0x00
,0x00,0x00,0x20,0x01,0x00,0x68,0x00,0x00,0x02,0x00,0x18,0x06,0x00,0x20,0x00,0x00
,0x00,0x00,0x0F,0x3C,0x00,0x20,0x00,0x00,0x00,0x00,0x01,0xE0,0x00,0x00,0x00,0x00
,0x00,0x60,0x00,0x00,0x00,0x00,0x00,0x00,0x00,0x00,0x00,0x00,0x00,0x00,0x00,0x00
,0x00,0x04,0x00,0x00,0x00,0x00,0x00,0x00,0x00,0x00,0x00,0x00,0x10,0x00,0x00,0x00
,0x00,0x00,0x60,0x03,0x00,0x00,0x00,0x00,0x00,0x00,0x06,0xB0,0x00,0x00,0x00,0x00
,0x00,0x00,0x00,0x80,0x00,0x00,0x00,0x00,0x07,0xCE,0x6D,0xDE,0x73,0xE0,0x00,0x00
,0x02,0x51,0x24,0x8A,0x89,0x20,0x00,0x00,0x02,0x5F,0x24,0x88,0x89,0x20,0x00,0x00
,0x02,0x50,0x24,0xA8,0x89,0x20,0x00,0x00,0x07,0x6F,0x3E,0xFC,0x73,0xB0,0x00,0x00
};
#define PROBE2_2_WIDTH  68
#define PROBE2_2_HEIGHT 56
#define PROBE2_2_X  30
#define PROBE2_2_Y 0
static unsigned char PROGMEM PROBE2_2[] = {
0x00,0x0B,0x80,0x00,0x00,0x00,0x00,0x00,0x00,0x00,0x60,0x60,0x00,0x00,0x00,0x07
,0xE0,0x00,0x00,0x80,0x18,0x00,0x00,0x00,0x18,0x30,0x00,0x00,0x80,0x0C,0x00,0x00
,0x00,0x20,0x10,0x00,0x00,0x80,0x06,0x00,0x00,0x00,0x40,0x10,0x00,0x01,0x80,0x02
,0x00,0x00,0x00,0xC0,0x10,0x00,0x00,0x80,0x01,0x00,0x00,0x00,0x80,0x30,0x00,0x00
,0xC0,0x01,0x80,0x00,0x00,0x80,0x20,0x00,0x00,0x60,0x00,0x80,0x00,0x00,0x80,0x3F
,0x80,0x0B,0xF0,0x00,0x80,0x00,0x01,0x80,0x00,0x40,0x10,0x18,0x00,0x80,0x00,0x00
,0x80,0x00,0x40,0x30,0x00,0x00,0x80,0x00,0x00,0x80,0x00,0x40,0x20,0x00,0x00,0x80
,0x00,0x03,0x00,0x00,0x40,0x20,0x00,0x01,0x80,0x00,0x04,0x00,0x00,0xC0,0x30,0x00
,0x01,0x80,0x00,0x08,0x00,0x00,0x80,0x20,0x00,0x00,0x40,0x00,0x30,0x00,0x01,0x00
,0x30,0x00,0x00,0x30,0x00,0x40,0x03,0x01,0x00,0x10,0x00,0x00,0x18,0x00,0x80,0x05
,0x82,0x00,0x18,0x00,0x00,0x06,0x03,0x00,0x04,0x6C,0x00,0x0C,0x0F,0x80,0x03,0x04
,0x00,0x18,0x00,0x00,0x06,0x10,0xC0,0x00,0x98,0x00,0x20,0x00,0x00,0x01,0xA0,0x20
,0x00,0xE0,0x00,0x40,0x00,0x00,0x00,0x00,0x18,0x00,0x40,0x01,0x80,0x00,0x00,0x00
,0x00,0x0C,0x01,0x80,0x02,0x00,0x00,0x00,0x00,0x00,0x06,0x02,0x00,0x04,0x00,0x00
,0x00,0x00,0x00,0x01,0x8C,0x00,0x08,0x00,0x00,0x00,0x00,0x00,0x00,0xD0,0x00,0x30
,0x00,0x00,0x00,0x00,0x00,0x00,0x60,0x00,0x60,0x00,0x00,0x00,0x00,0x00,0x00,0x40
,0x00,0xB0,0x00,0x00,0x00,0x00,0x00,0x01,0x80,0x03,0x08,0x00,0x00,0x00,0x00,0x00
,0x02,0x00,0x04,0x06,0x00,0x00,0x00,0x00,0x00,0x04,0x00,0x08,0x03,0x00,0x00,0x00
,0x00,0x00,0x18,0x00,0x10,0x01,0x80,0x00,0x00,0x00,0xDE,0x20,0x00,0x60,0x00,0xC0
,0x00,0x00,0x02,0x01,0xA0,0x00,0xB0,0x00,0x60,0x00,0x00,0x0C,0x00,0x80,0x01,0x0C
,0x00,0x18,0x00,0x00,0x10,0x00,0x00,0x06,0x06,0x00,0x0C,0x28,0x00,0x20,0x00,0x00
,0x08,0x01,0x00,0x06,0xAE,0x00,0x20,0x00,0x00,0x10,0x00,0xC0,0x02,0x01,0x80,0x40
,0x00,0x00,0x20,0x00,0x60,0x00,0x00,0xC0,0x40,0x00,0x00,0xC0,0x00,0x18,0x00,0x00
,0x60,0xC0,0x00,0x01,0x00,0x00,0x08,0x00,0x00,0x20,0x80,0x00,0x06,0x00,0x00,0x06
,0x00,0x00,0x30,0x80,0x00,0x08,0x00,0x00,0x01,0x80,0x00,0x10,0xC0,0x00,0x18,0x00
,0x00,0x00,0xC0,0x00,0x10,0x40,0x60,0x20,0x00,0x00,0x00,0x38,0x00,0x20,0x60,0xC0
,0x30,0x00,0x00,0x00,0x10,0x0E,0x20,0x37,0x80,0x10,0x00,0x00,0x00,0x10,0x0A,0x80
,0x00,0x80,0x18,0x00,0x00,0x00,0x30,0x0C,0x00,0x01,0x80,0x08,0x00,0x00,0x00,0x20
,0x04,0x00,0x01,0x00,0x08,0x00,0x00,0x00,0x20,0x04,0x00,0x01,0x00,0x18,0x00,0x00
,0x00,0x30,0x06,0x00,0x01,0x00,0x10,0x00,0x00,0x00,0x18,0x02,0x00,0x01,0x80,0x20
,0x00,0x00,0x00,0x0E,0x04,0x00,0x00,0xE0,0x40,0x00,0x00,0x00,0x01,0xD8,0x00,0x00
,0x1F,0x00,0x00,0x00,0x00,0x00,0x00,0x00};
#define PROBE2_3_WIDTH  55
#define PROBE2_3_HEIGHT 56
#define PROBE2_3_X  37
#define PROBE2_3_Y 0
static unsigned char PROGMEM PROBE2_3[] = {
0x01,0x00,0x00,0x10,0x00,0x01,0x00,0x0F,0xE0,0x00,0xFE,0x00,0x0F,0xE0,0x1F,0xF0
,0x01,0xFF,0x00,0x1F,0xF0,0x3F,0xF8,0x03,0xFF,0x80,0x3F,0xF8,0x7F,0xFC,0x07,0xFF
,0xC0,0x7F,0xFC,0x7F,0xFC,0x07,0xFF,0xC0,0x7F,0xFC,0xFF,0xFC,0x07,0xFF,0xC0,0x7F
,0xFE,0xFF,0xFE,0x0F,0xFF,0xE0,0x7F,0xFC,0x7F,0xFC,0x07,0xFF,0xC0,0x7F,0xFE,0x7F
,0xFC,0x07,0xFF,0xC0,0x7F,0xFC,0x7F,0xF8,0x07,0xFF,0xC0,0x7F,0xFC,0x3F,0xF8,0x03
,0xFF,0x80,0x3F,0xF8,0x1F,0xF0,0x01,0xFF,0x00,0x1F,0xF8,0x0F,0xE0,0x01,0xFE,0x00
,0x0F,0xE0,0x02,0x80,0x00,0x28,0x00,0x02,0x80,0x00,0x00,0x00,0x00,0x00,0x00,0x00
,0x00,0x00,0x00,0x00,0x00,0x00,0x00,0x00,0x00,0x00,0x00,0x00,0x00,0x00,0x00,0x00
,0x00,0x00,0x00,0x00,0x00,0x00,0x00,0x00,0x00,0x00,0x00,0x00,0x00,0x00,0x00,0x00
,0x00,0x00,0x00,0x01,0x00,0x00,0x10,0x00,0x01,0x00,0x0F,0xE0,0x00,0xFE,0x00,0x0F
,0xE0,0x1F,0xF0,0x01,0xFF,0x00,0x1F,0xF0,0x3F,0xF8,0x03,0xFF,0x80,0x3F,0xF8,0x7F
,0xF8,0x07,0xFF,0xC0,0x7F,0xFC,0x7F,0xFC,0x07,0xFF,0xC0,0x7F,0xFC,0xFF,0xFC,0x07
,0xFF,0xC0,0x7F,0xFC,0xFF,0xFE,0x0F,0xFF,0xE0,0x7F,0xFE,0xFF,0xFC,0x07,0xFF,0xC0
,0x7F,0xFC,0x7F,0xFC,0x07,0xFF,0xC0,0x7F,0xFC,0x7F,0xFC,0x07,0xFF,0xC0,0x7F,0xFC
,0x3F,0xF8,0x03,0xFF,0x80,0x3F,0xF8,0x3F,0xF0,0x03,0xFF,0x00,0x1F,0xF0,0x0F,0xE0
,0x00,0xFE,0x00,0x0F,0xE0,0x03,0x40,0x00,0x34,0x00,0x03,0x40,0x00,0x00,0x00,0x00
,0x00,0x00,0x00,0x00,0x00,0x00,0x00,0x00,0x00,0x00,0x00,0x00,0x00,0x00,0x00,0x00
,0x00,0x00,0x00,0x00,0x00,0x00,0x00,0x00,0x00,0x00,0x00,0x00,0x00,0x00,0x00,0x01
,0x00,0x00,0x00,0x00,0x00,0x00,0x0F,0xC0,0x00,0x76,0x00,0x06,0xE0,0x1F,0xF0,0x01
,0x00,0x00,0x10,0x10,0x3F,0xF8,0x02,0x00,0x80,0x20,0x08,0x7F,0xF8,0x04,0x00,0x40
,0x00,0x04,0x7F,0xFC,0x00,0x00,0x40,0x40,0x00,0xFF,0xFC,0x04,0x00,0x00,0x40,0x02
,0xFF,0xFE,0x08,0x00,0x20,0x00,0x00,0xFF,0xFC,0x00,0x00,0x40,0x40,0x02,0x7F,0xFC
,0x04,0x00,0x40,0x00,0x04,0x7F,0xFC,0x04,0x00,0x00,0x40,0x00,0x3F,0xF8,0x00,0x00
,0x80,0x20,0x04,0x3F,0xF0,0x02,0x00,0x80,0x00,0x08,0x0F,0xE0,0x01,0x42,0x00,0x14
,0x20,0x02,0x80,0x00,0x34,0x00,0x03,0x40};
#define PROBE2_4_WIDTH  79
#define PROBE2_4_HEIGHT 56
#define PROBE2_4_X  25
#define PROBE2_4_Y 0
static unsigned char PROGMEM PROBE2_4[] = {
0x00,0x00,0x00,0x00,0x00,0x00,0x00,0x00,0x00,0x00,0x00,0x00,0x00,0x00,0x00,0x00
,0x00,0x00,0x00,0x00,0x00,0x00,0x00,0x00,0x00,0x00,0x00,0x00,0x00,0x00,0x00,0x00
,0x00,0x00,0x00,0x00,0x00,0x00,0x00,0x00,0x00,0x00,0x00,0x00,0x00,0x00,0x00,0x00
,0x00,0x00,0x00,0x00,0x00,0x00,0x00,0x10,0x00,0x00,0x00,0x00,0x00,0x00,0x00,0x00
,0x00,0x18,0x00,0x00,0x00,0x00,0x00,0x00,0x00,0x00,0x00,0x18,0x00,0x00,0x00,0x00
,0x00,0x00,0x00,0x00,0x00,0x18,0x00,0x00,0x00,0x00,0x00,0x00,0x00,0x00,0x00,0x18
,0x00,0x00,0x00,0x00,0x00,0x00,0x00,0x00,0x00,0x18,0x00,0x00,0x00,0x00,0x00,0x00
,0x00,0x00,0x00,0x18,0x00,0x00,0x00,0x00,0x00,0x00,0x00,0x00,0x00,0x10,0x00,0x00
,0x00,0x00,0x00,0x00,0x00,0x00,0x00,0x10,0x00,0x00,0x00,0x00,0x00,0x00,0x00,0x00
,0x00,0x08,0x00,0x00,0x00,0x00,0x00,0x00,0x00,0x00,0x00,0x18,0x00,0x00,0x00,0x00
,0x00,0x00,0x00,0x00,0x00,0x08,0x00,0x00,0x00,0x00,0x00,0x00,0x00,0x00,0x00,0x30
,0x00,0x00,0x00,0x00,0x00,0x00,0x00,0x00,0x00,0x08,0x00,0x00,0x00,0x00,0x00,0x00
,0x00,0x00,0x00,0x34,0x00,0x00,0x00,0x00,0x00,0x00,0x00,0x00,0x00,0x08,0x00,0x00
,0x00,0x00,0x00,0x00,0x00,0x00,0x00,0x30,0x00,0x00,0x00,0x00,0x00,0x00,0x00,0x00
,0x00,0x3C,0x00,0x00,0x00,0x00,0x00,0x00,0x00,0x00,0x00,0x18,0x00,0x00,0x00,0x00
,0x00,0x00,0x00,0x00,0x00,0x14,0x00,0x00,0x00,0x00,0x00,0x00,0x00,0x00,0x00,0x3C
,0x00,0x00,0x00,0x00,0x00,0x00,0x00,0x00,0x00,0x00,0x00,0x00,0x00,0x00,0x00,0x00
,0x00,0x00,0x00,0x3C,0x00,0x00,0x00,0x00,0x00,0x00,0x00,0x00,0x00,0x08,0x00,0x00
,0x00,0x00,0x00,0x00,0x00,0x00,0x00,0x54,0x00,0x00,0x00,0x00,0x00,0x00,0x00,0x00
,0x00,0x18,0x00,0x00,0x00,0x00,0x00,0x00,0x00,0x00,0x00,0x52,0x00,0x00,0x00,0x00
,0x00,0x00,0x00,0x00,0x00,0x5A,0x00,0x00,0x00,0x00,0x00,0x00,0x00,0x00,0x00,0x12
,0x00,0x00,0x00,0x00,0x00,0x00,0x00,0x00,0x00,0x28,0x00,0x00,0x00,0x00,0x00,0x00
,0x00,0x00,0x00,0xFE,0x00,0x00,0x00,0x00,0x00,0x00,0x00,0x00,0x00,0xFF,0x00,0x00
,0x00,0x00,0x00,0x00,0x00,0x00,0x00,0x6E,0x00,0x00,0x00,0x00,0x00,0x00,0x00,0x00
,0x00,0xE7,0x00,0x00,0x00,0x00,0x00,0x00,0x00,0x00,0x00,0xC7,0x00,0x00,0x08,0x00
,0x00,0x00,0x00,0x00,0x00,0xC3,0x00,0x00,0x08,0x00,0x00,0x00,0x00,0x00,0x01,0xC3
,0x00,0x00,0x1C,0x00,0x00,0x00,0x00,0x00,0x01,0xC3,0x80,0x00,0x3E,0x00,0x00,0x00
,0x00,0x00,0x01,0x83,0x80,0x00,0x3E,0x00,0x00,0x00,0x00,0x00,0x01,0xC1,0x80,0x00
,0x3F,0x00,0x12,0x00,0x00,0x00,0x07,0xFF,0xE0,0x00,0x7F,0x00,0xFE,0x00,0x00,0x00
,0x07,0xFF,0xE0,0x02,0x3F,0x80,0xFC,0x00,0x07,0xFC,0x07,0xFF,0xC0,0x01,0x7F,0xA0
,0xFF,0xC0,0x07,0xFC,0x07,0xFF,0xE0,0x03,0x7F,0xE0,0xFD,0xE3,0x87,0xF8,0x0F,0xD7
,0xF0,0x07,0xFF,0xE0,0xFF,0xF3,0xC7,0x1C,0x0E,0x00,0x78,0x0F,0xFF,0xF6,0xFF,0xF7
,0xE7,0x1C,0x1E,0xA0,0x7A,0x9F,0xFF,0xFE,0xFF,0xFF,0xF7,0x1D,0xFF,0xFE,0x3F,0x7F
,0xFF,0xFE,0xFF,0xFF,0xFF,0x1F,0xFF,0xFF,0xFF,0xFF,0xFF,0xFE,0xFF,0xFF,0xFF,0x1F
,0xFF,0xFF,0xFF,0xFF,0xFF,0xFE,0xFF,0xFF,0xFF,0xFF,0xFF,0xFF,0xFF,0xFF,0xFF,0xFE
};
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
void loop()
{
  damageSplashScreen();
  while ('F' != runMode)
  {
    memset(entry, 0, sizeof(entry));
    cyclePictureDataEntry(entry, 11);
    if (!handleEntry(entry))
    {
      printBadEntry();
    }
  }
  doFinal();
}

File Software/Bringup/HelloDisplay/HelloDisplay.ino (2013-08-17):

/*********************************************************************
This is an example for our Monochrome OLEDs based on SSD1306 drivers

  Pick one up today in the adafruit shop!
  ------> http://www.adafruit.com/category/63_98

This example is for a 128x64 size display using SPI to communicate
4 or 5 pins are required to interface

Adafruit invests time and resources providing this open source code, 
please support Adafruit and open-source hardware by purchasing 
products from Adafruit!

Written by Limor Fried/Ladyada  for Adafruit Industries.  
BSD license, check license.txt for more information
All text above, and the splash screen must be included in any redistribution
*********************************************************************/

#include <Wire.h>
#include <Adafruit_GFX.h>
#include <Adafruit_SSD1306.h>

#define OLED_DC A2
#define OLED_CS A4
#define OLED_CLK A1
#define OLED_MOSI A0
#define OLED_RESET A3
Adafruit_SSD1306 display(OLED_MOSI, OLED_CLK, OLED_DC, OLED_RESET, OLED_CS);

#define NUMFLAKES 10
#define XPOS 0
#define YPOS 1
#define DELTAY 2

#define LOGO16_GLCD_HEIGHT 16 
#define LOGO16_GLCD_WIDTH  16 
static unsigned char PROGMEM logo16_glcd_bmp[] =
{ B00000000, B11000000,
  B00000001, B11000000,
  B00000001, B11000000,
  B00000011, B11100000,
  B11110011, B11100000,
  B11111110, B11111000,
  B01111110, B11111111,
  B00110011, B10011111,
  B00011111, B11111100,
  B00001101, B01110000,
  B00011011, B10100000,
  B00111111, B11100000,
  B00111111, B11110000,
  B01111100, B11110000,
  B01110000, B01110000,
  B00000000, B00110000 };

#if (SSD1306_LCDHEIGHT != 64)
#error("Height incorrect, please fix Adafruit_SSD1306.h!");
#endif

void setup()   {                
  Serial.begin(9600);
  
  // by default, we'll generate the high voltage from the 3.3v line internally! (neat!)
  display.begin(SSD1306_SWITCHCAPVCC);
  // init done
  
  display.display(); // show splashscreen
  delay(2000);
  display.clearDisplay();   // clears the screen and buffer

  // draw a single pixel
  display.drawPixel(10, 10, WHITE);
  display.display();
  delay(2000);
  display.clearDisplay();

  // draw many lines
  testdrawline();
  display.display();
  delay(2000);
  display.clearDisplay();

  // draw rectangles
  testdrawrect();
  display.display();
  delay(2000);
  display.clearDisplay();

  // draw multiple rectangles
  testfillrect();
  display.display();
  delay(2000);
  display.clearDisplay();

  // draw mulitple circles
  testdrawcircle();
  display.display();
  delay(2000);
  display.clearDisplay();

  // draw a white circle, 10 pixel radius
  display.fillCircle(display.width()/2, display.height()/2, 10, WHITE);
  display.display();
  delay(2000);
  display.clearDisplay();

  testdrawroundrect();
  delay(2000);
  display.clearDisplay();

  testfillroundrect();
  delay(2000);
  display.clearDisplay();

  testdrawtriangle();
  delay(2000);
  display.clearDisplay();
   
  testfilltriangle();
  delay(2000);
  display.clearDisplay();

  // draw the first ~12 characters in the font
  testdrawchar();
  display.display();
  delay(2000);
  display.clearDisplay();

  // draw scrolling text
  testscrolltext();
  delay(2000);
  display.clearDisplay();
  
  // text display tests
  display.setTextSize(1);
  display.setTextColor(WHITE);
  display.setCursor(0,0);
  display.println("Hello, world!");
  display.setTextColor(BLACK, WHITE); // 'inverted' text
  display.println(3.141592);
  display.setTextSize(2);
  display.setTextColor(WHITE);
  display.print("0x"); display.println(0xDEADBEEF, HEX);
  display.display();
  delay(2000);

  // miniature bitmap display
  display.clearDisplay();
  display.drawBitmap(30, 16,  logo16_glcd_bmp, 16, 16, 1);
  display.display();

  // invert the display
  display.invertDisplay(true);
  delay(1000); 
  display.invertDisplay(false);
  delay(1000); 

  // draw a bitmap icon and 'animate' movement
  testdrawbitmap(logo16_glcd_bmp, LOGO16_GLCD_HEIGHT, LOGO16_GLCD_WIDTH);
}


void loop() {
  
}


void testdrawbitmap(const uint8_t *bitmap, uint8_t w, uint8_t h) {
  uint8_t icons[NUMFLAKES][3];
  srandom(666);     // whatever seed
 
  // initialize
  for (uint8_t f=0; f< NUMFLAKES; f++) {
    icons[f][XPOS] = random() % display.width();
    icons[f][YPOS] = 0;
    icons[f][DELTAY] = random() % 5 + 1;
    
    Serial.print("x: ");
    Serial.print(icons[f][XPOS], DEC);
    Serial.print(" y: ");
    Serial.print(icons[f][YPOS], DEC);
    Serial.print(" dy: ");
    Serial.println(icons[f][DELTAY], DEC);
  }

  while (1) {
    // draw each icon
    for (uint8_t f=0; f< NUMFLAKES; f++) {
      display.drawBitmap(icons[f][XPOS], icons[f][YPOS], logo16_glcd_bmp, w, h, WHITE);
    }
    display.display();
    delay(200);
    
    // then erase it + move it
    for (uint8_t f=0; f< NUMFLAKES; f++) {
      display.drawBitmap(icons[f][XPOS], icons[f][YPOS],  logo16_glcd_bmp, w, h, BLACK);
      // move it
      icons[f][YPOS] += icons[f][DELTAY];
      // if its gone, reinit
      if (icons[f][YPOS] > display.height()) {
	icons[f][XPOS] = random() % display.width();
	icons[f][YPOS] = 0;
	icons[f][DELTAY] = random() % 5 + 1;
      }
    }
   }
}


void testdrawchar(void) {
  display.setTextSize(1);
  display.setTextColor(WHITE);
  display.setCursor(0,0);

  for (uint8_t i=0; i < 168; i++) {
    if (i == '\n') continue;
    display.write(i);
    if ((i > 0) && (i % 21 == 0))
      display.println();
  }    
  display.display();
}

void testdrawcircle(void) {
  for (int16_t i=0; i<display.height(); i+=2) {
    display.drawCircle(display.width()/2, display.height()/2, i, WHITE);
    display.display();
  }
}

void testfillrect(void) {
  uint8_t color = 1;
  for (int16_t i=0; i<display.height()/2; i+=3) {
    // alternate colors
    display.fillRect(i, i, display.width()-i*2, display.height()-i*2, color%2);
    display.display();
    color++;
  }
}

void testdrawtriangle(void) {
  for (int16_t i=0; i<min(display.width(),display.height())/2; i+=5) {
    display.drawTriangle(display.width()/2, display.height()/2-i,
                     display.width()/2-i, display.height()/2+i,
                     display.width()/2+i, display.height()/2+i, WHITE);
    display.display();
  }
}

void testfilltriangle(void) {
  uint8_t color = WHITE;
  for (int16_t i=min(display.width(),display.height())/2; i>0; i-=5) {
    display.fillTriangle(display.width()/2, display.height()/2-i,
                     display.width()/2-i, display.height()/2+i,
                     display.width()/2+i, display.height()/2+i, WHITE);
    if (color == WHITE) color = BLACK;
    else color = WHITE;
    display.display();
  }
}

void testdrawroundrect(void) {
  for (int16_t i=0; i<display.height()/2-2; i+=2) {
    display.drawRoundRect(i, i, display.width()-2*i, display.height()-2*i, display.height()/4, WHITE);
    display.display();
  }
}
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

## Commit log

2013-08-10 Add a basic Fritizing schematic
    [Chubby_Tricorder.fzz]
2013-08-10 Updated tasks, added schematic PNG export
2013-08-17 Hardware bringup
    Hello world for all the various components on their selected wires. Updated schematic to identify which pins on the Arduino go to which pins on the device.
    [Chubby_Tricorder.fzz]
2013-08-18 OLED board files
    [Adafruit_1.3_128x64_OLED.brd]
2013-08-18 OLED footprint AI
    Added AI file of just the OLED footprint without the board traces, etc.
2013-08-18 International power symbol
2013-08-18 case checkpoint
2013-08-26 Wireless
    First round of wireless. I'm sending ASCII characters now, but need to switch to square waves.
2013-08-31 A little further on the Plan B framework.
2013-08-31 Image rotation framework
2013-08-31 3D-Printed braces to help support the acrylic panel with the printer
    [3d_printed_brace-1.stl, 3d_printed_brace-2.stl, 3d_printed_brace-3.stl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]
2013-09-01 Reverse pinout of keypad matrix
    [HelloAll.ino]
2013-09-01 Moved 3D print files, added RF bracket
    [3d_printed_brace-1.stl, 3d_printed_brace-2.stl, 3d_printed_brace-3.stl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]
2013-09-01 RF module bracket
    [RF_Module_Bracket.scad, RF_Module_Bracket.stl]
2013-09-01 Tweaked the geometry slightly
    [RF_Module_Bracket.scad, RF_Module_Bracket.stl]
2013-09-01 Added RF module to schematic, reorg dirs
    [Adafruit_1.3_128x64_OLED.brd, Chubby_Tricorder.fzz]
2013-09-01 Sample RF RX hardward plate
2013-09-07 Final (or close to) Probe software
2013-09-08 Probe images
2013-09-14 Cleaned up memory usage/crashiness
    [Probe.ino]
